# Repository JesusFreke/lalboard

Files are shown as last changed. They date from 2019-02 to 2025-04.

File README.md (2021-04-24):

##### lalboard - A 3D-printed keyboard inspired by the DataHand.

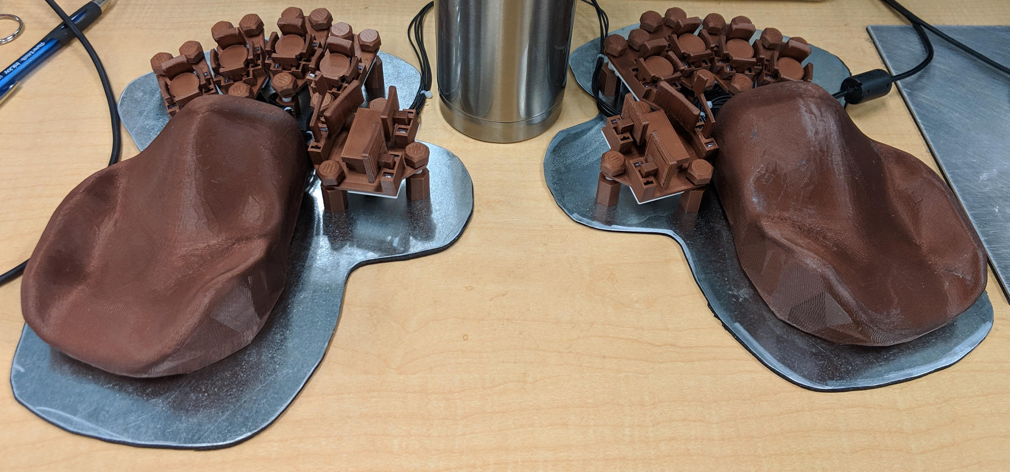
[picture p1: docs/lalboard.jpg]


## Links
[More Images](https://github.com/JesusFreke/lalboard/wiki/Images)

[120 WPM Typing Demo](https://www.youtube.com/watch?v=oMhOIgrdeE0)

[V2 Project Logs (hackaday.io)](http://lalboard.com)

Online viewer for cluster assemblies:
- [finger](https://a360.co/3vxlLLL)
- [left thumb](https://a360.co/3c63TzE)
- [right thumb](https://a360.co/3c6tvws)

## Project Details
I am a long-time user of a DataHand keyboard. With the scarcity and rising cost of second hand
DataHands these days, I wanted to ensure that I always had access to a DataHand-like keyboard. And
so this project was born.

The overall functionality of the lalboard is obviously heavily based on the DataHand, but I designed
all of the specific key mechanisms, etc. from scratch, to be printable on a normal hobby-level
FDM printer.

With my DataHand, I never felt like I could get the keys positioned *quite right* for my hand. So
one of my primary focuses with the lalboard was adjustability. Each key cluster can be independently
adjusted in all 6 degrees of freedom to some extent.

Most parts need to be printed in a very opaque PLA, but there are a few parts that don't work well
in PLA which should be printed in polycarbonate or similar material, for its strength and heat
resistance.

##### Key Mechanisms

All keys use a pair of magnets to provide the clickiness and key return force, and an IR LED and
phototransistor for detecting a keypress. They are all held in place only with magnets, so they
are easily removable for cleaning, etc.

The feel/clickiness of the keys was another focus area. I tried to get them to feel as similar to
those on a DataHand as possible. They require roughly the same amount of force, and have that same
unique clicky feel due to the magnetic holding force.

##### Adjustability

The key clusters have a trio of standoffs that are designed to be mounted onto a steel sheet with
magnets. Each standoff has an adjustable height, and is mounted to the key cluster via a
ball socket. This provides a limited 6 degrees of freedom in adjusting the angle and position of
each key cluster, in order to get it perfectly positioned for your hands.

##### Electronics

This design uses copper traces that are cut from adhesive-backed copper tape using a vinyl cutter,
and applied to the bottom of 3D-printed "pcbs" printed with polycarbonate for its excellent heat
resistance during soldering. There are currently no designs for actual pcbs, but I don't think it
should be difficult to do. If someone wants to tackle that, I'm happy to give pointers or otherwise
help in any way I can :)

Each side of the keyboard uses an independent teensy 2.0 board, and are connected with 4 wires
between them to enable communication via i2c. Only one side of the keyboard actually needs to be
plugged into USB. The teensy's run a modified version of the
[teensyhand](https://github.com/JesusFreke/teensyhand) firmware.

##### Handrest

The handrest was first molded for my wrist in plasticine clay, and then scanned in using the
[meshroom](https://github.com/alicevision/meshroom) photogrammetry software. Since they were molded
for my wrists specifically, I'm not sure how "one-size-fits-all" they are, or how comfortable they
would be for someone else to use.

##### [BOM](https://github.com/JesusFreke/lalboard/wiki/BOM)

##### [Printing tips & instructions](https://github.com/JesusFreke/lalboard/wiki/Printing-tips-&-instructions)

##### [Preparing the Vinyl-cut PCBs](https://github.com/JesusFreke/lalboard/wiki/Vinyl-Cut-PCBs)

--------

Note: This is not an officially supported Google product.

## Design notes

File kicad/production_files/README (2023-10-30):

For generating gerbers: https://jlcpcb.com/help/article/362-how-to-generate-gerber-and-drill-files-in-kicad-7
For generating BOM/CPL: https://dubiouscreations.com/2019/10/21/using-kicad-with-jlcpcb-assembly-service/

tweaks to CPL file:

J1-J7 - remove
J8, J9 - 180 degrees, subtract 1.75 from Y position
U6, U7 - check rotation
U2 - check rotation
Y1 - check rotation

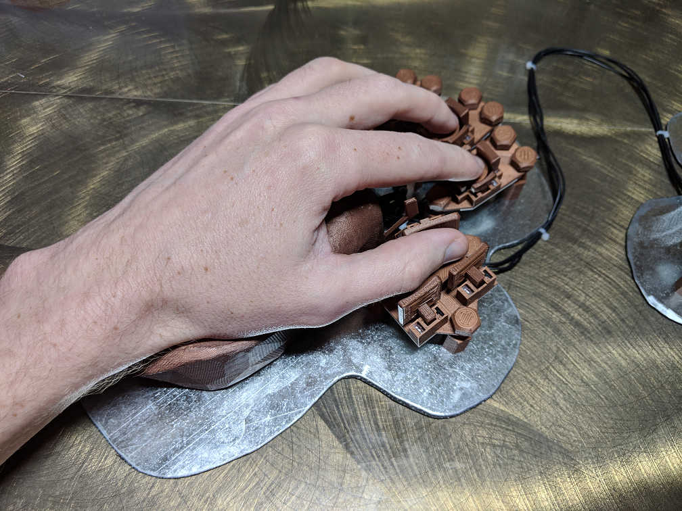
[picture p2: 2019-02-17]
docs/hand.jpg

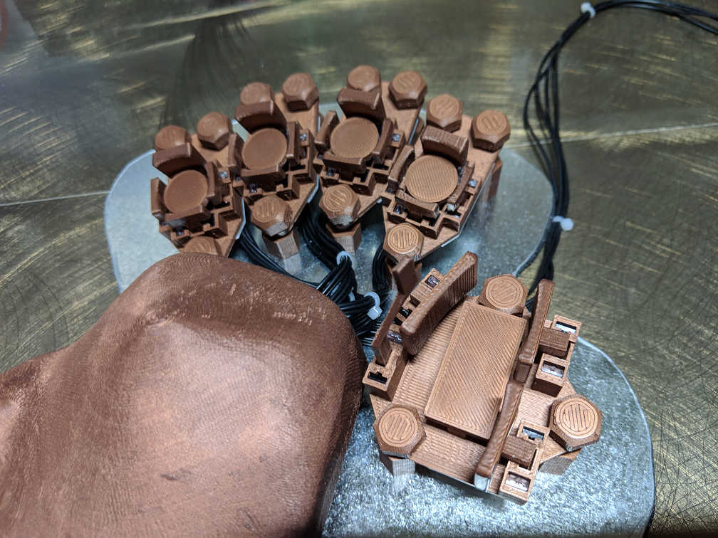
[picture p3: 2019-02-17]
docs/closeup.jpg

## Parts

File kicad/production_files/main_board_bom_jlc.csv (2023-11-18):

Comment | Designator | Footprint | LCSC Part Number
10u | C1 | C_0402_1005Metric | C15525
100n | C2,C5,C6,C9,C12,C13,C14,C15,C16,C17,C19,C20 | C_0402_1005Metric | C307331
4.7u | C4 | C_0402_1005Metric | C23733
1u | C7,C10 | C_0402_1005Metric | C307454
30pF | C8,C11 | C_0402_1005Metric | C1570
CBG201209U500T | FB1,FB2,FB3,FB4 | L_0805_2012Metric | C668236
TYPE-C-31-M-12 | J8,J9 | USB_C_Receptacle_HRO_TYPE-C-31-M-12 | C165948
DMG2301L-7 | Q1,Q2,Q3,Q4,Q5 | SOT-23 | C102619
1.5k | R1 | R_0402_1005Metric | C25867
1k | R2,R3 | C_0402_1005Metric | C11702
10k | R4 | R_0402_1005Metric | C25744
27 | R5,R6 | C_0402_1005Metric | C25100
100k | R7 | R_0402_1005Metric | C25741
390k | R8 | R_0402_1005Metric | C25782
2k | R9,R10,R11,R12,R13 | R_0402_1005Metric_Pad0.72x0.64mm_HandSolder | C4109
5.1k | R14,R15,R16,R17 | R_0402_1005Metric | C25905
Reset | SW1 | SW_TS-1187A-B-A-B | C318884
Boot | SW2 | SW_TS-1187A-B-A-B | C318884
XC6220B331MR | U1 | SOT-23-5 | C3040644
RP2040 | U2 | RP2040-QFN-56 | C2040
W25Q128JVS | U3 | SOIC-8_5.23x5.23mm_P1.27mm | C97521
COS724 | U4,U5 | TSSOP-14_4.4x5mm_P0.65mm | C2685541
USBLC6-2SC6 | U6,U7 | SOT-23-6 | C7519
Crystal_GND24 | Y1 | OSC_X322516MLB4SI | C9002

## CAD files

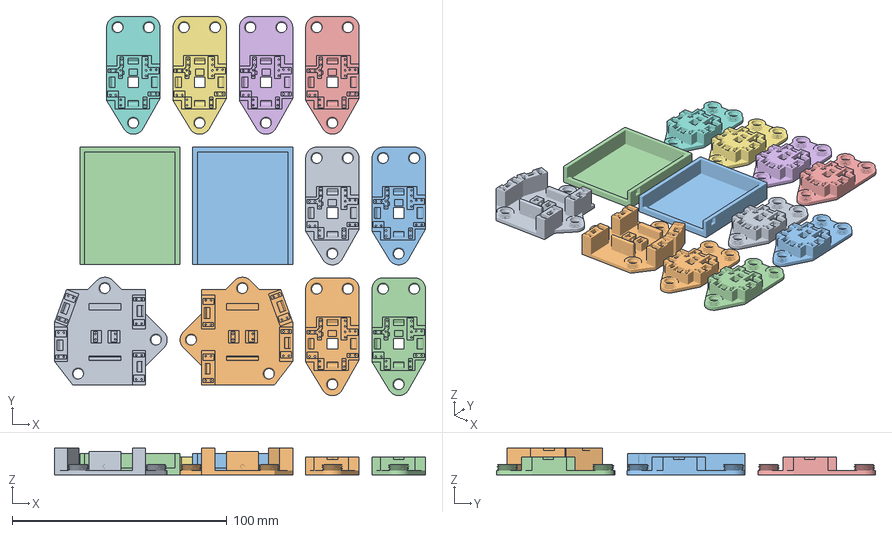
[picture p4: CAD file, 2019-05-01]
configs/clusters.3mf
172.8 x 176.6 x 12.4 mm
cluster.stl
left_thumb_cluster.stl
right_thumb_cluster.stl
central_pcb_tray.stl

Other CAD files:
left_handrest.f3d
test/FingerClusterPlacementTest/absolute_cartesian_and_euler_placement.f3d
test/FingerClusterPlacementTest/absolute_cylindrical_and_support_lengths_placement.f3d
test/FingerClusterPlacementTest/lefthand_relative_cartesian_placement.f3d
test/FingerClusterPlacementTest/lefthand_relative_cartesian_placement_with_gap.f3d
test/FingerClusterPlacementTest/lefthand_relative_cylindrical_placement.f3d
test/FingerClusterPlacementTest/lefthand_relative_cylindrical_placement_with_gap.f3d
test/FingerClusterPlacementTest/righthand_relative_cartesian_placement.f3d
test/FingerClusterPlacementTest/righthand_relative_cartesian_placement_with_gap.f3d
test/FingerClusterPlacementTest/righthand_relative_cylindrical_placement.f3d
test/FingerClusterPlacementTest/righthand_relative_cylindrical_placement_with_gap.f3d
test/ThumbClusterPlacementTest/absolute_cartesian_and_euler_placement_left.f3d
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

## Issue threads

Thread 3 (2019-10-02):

Please create a Kickstarter/Indiegogo/etc

hillelcoren, 2019-10-02:
I would love to buy one of these, how can I help make it happen?

JesusFreke, 2019-10-02:
haha, no :)

I'm happy to put the design up and let people do what they want with it, but I don't particularly want to spend my free time trying to finagle a crowd funding campaign, or building these to sell. Plus, it's honestly not... polished enough to be sold/marketed as an off-the-shelf consumer item.

I might be convinced to sell the raw 3d printed/vinyl cut parts or something though.

Closed 2019-11-05.

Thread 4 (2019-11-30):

7 pin cable length

fi0, 2019-11-30:
I found a source for 7-pin silicone wire with ZH 1.5. How long should I buy? is 6" long enough?

JesusFreke, 2019-11-30:
See https://github.com/JesusFreke/lalboard/wiki/BOM. You'll want 10x of the 6" ones, and one longer one. The longer one is the one that runs between the two sides. I would say probably a minimum of 10" for that one, but 12" or even longer may be better. The longer it is the further apart you can have the 2 sides, of course.

JesusFreke, 2019-11-30:
Also, care to share the source? :) I can add it to the BOM page

HeuristicBishop, 2019-12-03:
I would also greatly appreciate a source!

fi0, 2019-12-03:
Thank you for the clarifications! I'm going to place a custom order from a factory in China.

HeuristicBishop, 2020-04-13:
Not the cheapest in the world but non-silicon premade jumpers can be sourced from digi-key:
Part number: A07ZR07ZR28H102B

JesusFreke, 2020-04-13:
Yeah, the BOM includes links to at least some 150mm cables with PVC insulation. I found a similar 1'/300mm digikey cable and added a link to the BOM.

They'll definitely work, but it's a bit of a pain working with them in such a confined space.

I wasn't familiar with the ZR line. It looks like they're a "press in" connector, that is compatible with the ZH sockets. Interesting. They may be significantly quicker and easier to use when making your own cables, since you don't have painstakingly crimp each individual wire twice. I'll have to try them out.

Closed 2019-12-03.

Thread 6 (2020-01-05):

Wiring tutorials?

GeneralMidi, 2020-01-05:
Hi, this project looks great, maybe not so for a noob. But we'll see. I wasn't able to find any wiring diagrams, or images for wiring the components on your github. Would you point me in the right direction? Thanks.

JesusFreke, 2020-01-05:
The only wires are the ones that run between each cluster and the central board for each hand. And then the ones that run between the two hands. There's a 7-pin jst-zh connector on each cluster, and on each board, and you just plug the wire connector in to either side.

Each cluster, etc. has a little "circuit board" thing, made out of vinyl-cut copper. You can find more information about how I made those on the [wiki page](https://github.com/JesusFreke/lalboard/wiki/Vinyl-Cut-PCBs).

GeneralMidi, 2020-01-06:
Thanks so much for your response, and please excuse my very low experience level. I couldn't find how you wire up the IR leds, photo transistors, the sink drivers, smd resistors, teensys etc. Sorry if this is straight forward, I just like to have a clear idea in my mind how the pieces fit together before I tackle such a project! Thanks for making the project available by the way.

l4u, 2020-01-06:
@GeneralMidi
see https://github.com/JesusFreke/lalboard/blob/master/eagle/mapping.pdf and https://github.com/JesusFreke/lalboard/tree/master/vinyl_cut_pcb for the wiring :)

GeneralMidi, 2020-01-06:
Noob! Thanks so much for pointing me in the right direction...

ampleyfly, 2020-08-13:
I also find the wiring confusing, even given the mapping and the wiki here on Github.
The Eagle files for the center board helps clear that part of it up, but the vinyl cut PCB:s are harder for me to get.
In the mapping.pdf file linked above, the PCB seen to the top left is that for the right thumb, which as far as I can tell is wired differently than the one for the left thumb.
It is also unclear to me which orientation the JST connector has when the thumb or finger boards are viewed from the top. Is pin 1 to the right or to the left?
To help myself sort this out, I have been tinkering with kicad PCB:s for the thumb and finger boards, as well as a wiring diagram using WireViz. Would that be of use to you guys, once I get it down?

JesusFreke, 2020-08-14:
As far as I can tell, the datasheet for the connectors doesn't specify a pin numbering scheme, so there is no common "pin 1" reference to help orient.

The 3d printed part for the pcbs for the individual finger clusters are sized so that the back edge of the connector is flush with the back edge of the pcb in one of the orientations. And with it in that orientation, it gives a tiny bit more space to solder the through-wires just in front if it. But at the end of the day, the orientation doesn't really matter.

There are 3 variables in play - the orientation of both connectors, plus how the wire is... wired (straight-through or reverse). Any combination of those three variables that is mechanically feasible, and ends up with the right pins being connected should work.

I have definitely accidentally soldered connectors backward, and "fixed" it by either soldering the corresponding connector on the central pcb the opposite way, or by reversing how the wire is wired.

That being said, I think the connector pins in the svgs could probably use some labels, so you don't have to try to manually trace things based on known voltage/ground/data pins elsewhere in the circuit.

I would be happy to include any documentation you write and think would be useful :). Either in the project itself (pull request), or in the wiki (PM me and I can add you as a collaborator, allowing you to edit the wiki)

JesusFreke, 2020-08-14:
And yes, the left and right thumbs are wired differently. For one thing, the LEDs and phototransistors are in opposite positions per-key on each side (why?... heck if I know! I didn't even notice that until just now). But even if if they weren't, if you tried to use a mirror copy of the pcb, the components would be wired up in the wrong polarity, since the components themselves aren't mirrored.

JesusFreke, 2020-08-14:
More labels were added in 4e3174a545aaef074abca677f9573e4fc0cdbc51. Hopefully that should make it a bit easier to read :)

JesusFreke, 2020-08-24:
@ampleyfly - I haven't fully looked at everything yet, but it looks like the thumb connector on the central pcb is wired incorrectly. For example, the middle pin should be ground, and 5V should be beside it. But it is wired with the same connections as the finger clusters, with ground and 5V at 1 and 6 (or 7 and 2, depending on which way you number it).

Also, it looks like the thumb and finger boards are 4 layers? It should be possible to do it with 2 layers, which should typically make it cheaper, I would think.

ampleyfly, 2020-08-24:
The central board is imported from the eagle project, and the pinnings on the finger and thumb boards are based on the svg files. Perhaps this mismatch explains the confusion about the wiring in the first place?

I did it in 4 layers because it is a lot easier and takes less effort. While there is a difference in price, 4 layers is still pretty cheap. One the wiring is nailed down, the pcbs could be converted to 2 layers.

ampleyfly, 2020-08-26:
I just realised that the eagle files comes from a pull request from the @IronFox fork, where there are also files for the other pcb:s. I guess either merging those or looking there for how to wire things is better tha redoing the work.

ampleyfly, 2020-08-27:
I updated my branch with a center pcb based on the svg file instead, so now it should at least reflect what's in the svgs accurately! :)

JesusFreke, 2020-08-27:
Yeah, @IronFox is doing his own thing - which is great! But I think not totally compatible.

@IronFox - I'm thinking I might remove the stuff you added in your first pull request to avoid confusion, since it doesn't appear to be compatible with the rest of the "stock" lalboard. But I'd be happy to add a pointer to your project/fork in the README!

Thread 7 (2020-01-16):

Custom handrest?

bofh, 2020-01-16:
Hello, could you please outline the process and provide some tips you used to mold custom handrest? What should be the optimal hand position, height above the table, etc.?

JesusFreke, 2020-01-16:
I molded it out of some plasticene clay first, and then scanned it in use the mesh photogrammetry software. I had never used it before, but used [the tutorial](https://www.youtube.com/watch?v=1D0EhSi-vvc) that Prusa published. Once it was scanned in, I think I cleaned up the mesh in the meshlab software, and then imported it into fusion 360 and simplified the mesh, and added the rectangular cutout in the bottom for the central electronics tray. I don't recall the exact process/steps offhand, sorry :)

As far as the shape, you can take a look at the existing hand rests to get an idea. It needs to be wide enough to hold the tray of course. But other than that, it's mostly up to personal taste? Just kinda whatever feels right for your hand. heh. I'm certainly no ergonomic specialist :)

I would recommend getting the finger and thumb clusters made and at least mechanically assembled and placed onto the steel sheet, and then molding the custom clay handrest in place, so you can see how it feels with your fingers actually in place on the keys, etc.

Closed 2020-04-04.

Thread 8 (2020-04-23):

CAD Models?

thecheatscalc, 2020-04-23:
I apologize if these are available somewhere, but would you be interested in adding your CAD models that generated the STLs? If they're hosted elsewhere, would you mind adding a link in the docs?

JesusFreke, 2020-04-23:
lalboard.py is where all of the models are defined. It uses my [fscad framework](fscad.org) for fusion 360.

thecheatscalc, 2020-04-23:
Aha, I completely missed that. I'll have to try and pull the models in with your fscad framework later. Thanks for clarifying!

Closed 2020-04-23.

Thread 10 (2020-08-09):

Top level assembly

AntonEvmenenko, 2020-08-09:
Hi @JesusFreke!

Let me thank you for creating this very interesting project!

As I understand, you published the Fusion 360 scripts only for individual parts, but currently repository doesn't contain a script that would allow you to generate the entire keyboard:

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

If you added such a script, it would be very cool :)

Of course, if you have your own opinion about it (for example, you do not want to publish this project completely), then it's okay, in this case just close this issue please.

JesusFreke, 2020-08-09:
I did have some scripts for the individual cluster assemblies at one point, but they got out of date as things changed. But the entire project is published. I don't have some hidden script that I'm keeping from you ;)

AntonEvmenenko, 2020-08-10:
> I don't have some hidden script that I'm keeping from you ;)

Haha :)

Ok, thanks for your answer!

Closed 2020-08-10.

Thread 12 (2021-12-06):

Unable to build the Fusion 360 Model: TypeError: create() missing 1 required positional argument: 'z'

ripxorip, 2021-12-06:
Hi, super interesting project! I want to be able to simply build the model and poke around to see all the details in fusion 360. When I try to run the python script like this:

`

$env:PYTHONPATH = "C:\Users\ripxo\AppData\Roaming\Autodesk\Autodesk Fusion 360\API\Python\defs;C:\Users\ripxo\AppData\Roaming\Autodesk\Autodesk Fusion 360\API\AddIns\fscad_addin\src\fscad"

C:/Users/ripxo/AppData/Local/Autodesk/webdeploy/production/849db2e62eaf03702e1167dc7313a6f88a8f47d0/Python/python.exe .\lalboard.py

`

I get the following error:

`
Traceback (most recent call last):
  File ".\lalboard.py", line 27, in <module>
    from fscad import *
  File "C:\Users\ripxo\AppData\Roaming\Autodesk\Autodesk Fusion 360\API\AddIns\fscad_addin\src\fscad\fscad.py", line 1099, in <module>
    class Component(BoundedEntity, ABC):
  File "C:\Users\ripxo\AppData\Roaming\Autodesk\Autodesk Fusion 360\API\AddIns\fscad_addin\src\fscad\fscad.py", line 1121, in Component
    _origin = Point3D.create(0, 0, 0)
TypeError: create() missing 1 required positional argument: 'z'
`

Has the Fusion360 API got updated so that it is messing with fscad somehow? Thanks in advande

ripxorip, 2021-12-06:
I just realized when browsing through the code that the ....\defs folder appeared to be a mock of some kind so I updated the path:

$env:PYTHONPATH = "C:\Users\ripxo\AppData\Local\Autodesk\webdeploy\production\849db2e62eaf03702e1167dc7313a6f88a8f47d0\Api\Python\packages;C:\Users\ripxo\AppData\Roaming\Autodesk\Autodesk Fusion 360\API\AddIns\fscad_addin\src\fscad"

But now it fails to load some DLL:

`
Traceback (most recent call last):
  File ".\lalboard.py", line 20, in <module>
    import adsk.core
  File "C:\Users\ripxo\AppData\Local\Autodesk\webdeploy\production\849db2e62eaf03702e1167dc7313a6f88a8f47d0\Api\Python\packages\adsk\core.py", line 13, in <module>
    from . import _core
ImportError: DLL load failed: The specified module could not be found.
`

ripxorip, 2021-12-06:
(I am trying to run it straight from Powershell since it fails without any info when trying to run the script from within Fusion 360)

ripxorip, 2021-12-06:
I think I am getting somewhere... I have realized that you need IntelliJ and your plugins to inject in to Fusion 360. I have one through the hassle of downloading and installing IDEA and the plugins. I have set up the source of this repo as a project and configured it accordningly. When I now try to build the model I get the following error:

Unhandled exception while importing and running script.
Traceback (most recent call last):
  File "C:/Users/ripxo/AppData/Roaming/Autodesk/Autodesk Fusion 360/API/AddIns/fusion_idea_addin/fusion_idea_addin.py", line 340, in notify
    spec.loader.exec_module(module)
  File "<frozen importlib._bootstrap_external>", line 728, in exec_module
  File "<frozen importlib._bootstrap>", line 219, in _call_with_frames_removed
  File "C:\dev\lalboard\lalboard.py", line 516, in <module>
    def find_tangent_intersection_on_circle(circle: Circle, point: Point3D):
NameError: name 'Circle' is not defined

Seems like something is not imported correctly?

JesusFreke, 2021-12-06:
The script has to be run inside of fusion 360. The easiest way to do this is just by adding it as a script in the "scripts and add-ins" dialog. But if you want to get a full development environment set up, you can install intellij idea (community edition is fine) and use my [fusionidea plugin](https://github.com/JesusFreke/fusionIdea) to inject the script into fusion and run it that way. See [here](https://github.com/JesusFreke/fscad/wiki/Getting-started-with-Intellij-IDEA-(Windows)) for more details on that route - although it looks like this may be slightly out of date. I'll try and get it updated :)

In either case, you'll need to ensure that fscad has been installed in fusion 360. See https://github.com/JesusFreke/fscad/wiki/Installation

ripxorip, 2021-12-06:
Thanks for the reply. I have went down the route of the fusionidea plugin. And this:

Unhandled exception while importing and running script.
Traceback (most recent call last):
File "C:/Users/ripxo/AppData/Roaming/Autodesk/Autodesk Fusion 360/API/AddIns/fusion_idea_addin/fusion_idea_addin.py", line 340, in notify
spec.loader.exec_module(module)
File "", line 728, in exec_module
File "", line 219, in _call_with_frames_removed
File "C:\dev\lalboard\lalboard.py", line 516, in
def find_tangent_intersection_on_circle(circle: Circle, point: Point3D):
NameError: name 'Circle' is not defined

Is infact from Fusion 360 so I have a connection :) I have installed both plugins in Fusion 360, fscad and ideafusion. It seems that when running in Fusion 360 it is having a problem referecing classes from the "from fscad import *" ?

ripxorip, 2021-12-06:
My guess is that something goes wrong when adding the fscad plugin as a dependency?

JesusFreke, 2021-12-06:
Also note that the lalboard.py script itself doesn't actually create any parts. You'll need to run the script for an individual part or for an assembly, in the parts folder. See, e.g. [static_base_left_full_assembly](https://github.com/JesusFreke/lalboard/blob/v2_no_stls/parts/static_base_left_full_assembly/static_base_left_full_assembly.py), which should create the full left-hand side, using a "static" base.

ripxorip, 2021-12-06:
The script failed to run directly in Fusion 360 without any output, so thats why I continued my investigation and installed IntelliJ etc.

JesusFreke, 2021-12-06:
Are you sure fscad is installed as an add-in? And is the add-in running? You may need to set it to auto-run when fusion starts.

JesusFreke, 2021-12-06:
Also, make sure you're on the v2_no_stls branch :). I don't think the main (v1) branch is what you want at this point.

ripxorip, 2021-12-06:
Yeah fscad_addin is running and set to auto-start. Tried the steel_base_left_full_assembly now and it failed:

Unhandled exception while importing and running script.
Traceback (most recent call last):
  File "C:/Users/ripxo/AppData/Roaming/Autodesk/Autodesk Fusion 360/API/AddIns/fusion_idea_addin/fusion_idea_addin.py", line 342, in notify
    module.run({"isApplicationStartup": False})
AttributeError: module '__main__C%3A%5Cdev%5Clalboard%5Clalboard_py' has no attribute 'run'

ripxorip, 2021-12-06:
Yeah Im on the v2_no_stls now :)

JesusFreke, 2021-12-06:
Yeah, looking at the main branch, that Circle error makes sense, since fscad has been slightly restructured, so it requires slightly different imports now. Hopefully the v2_no_stls branch should work fine though.

JesusFreke, 2021-12-06:
Oh, you probably want to restart fusion at this point. Just to clear out any lingering loaded scripts from when you were using the main branch.

ripxorip, 2021-12-06:
Score! It works, managed to run the part manually without IntelliJ straight in Fursion360 :) However using IntelliJ:

Unhandled exception while importing and running script.
Traceback (most recent call last):
  File "C:/Users/ripxo/AppData/Roaming/Autodesk/Autodesk Fusion 360/API/AddIns/fusion_idea_addin/fusion_idea_addin.py", line 342, in notify
    module.run({"isApplicationStartup": False})
AttributeError: module '__main__C%3A%5Cdev%5Clalboard%5Clalboard_py' has no attribute 'run'

Still a win since I now can look at the full model in Fusion 360 :) Thank you very much for this project and for the support

JesusFreke, 2021-12-06:
It looks like it's still trying to run lalboard.py instead of the individual part script

ripxorip, 2021-12-06:
Correct, I am a IDEA noob... First time using it. Now it runs the part script:

Unhandled exception while importing and running script.
Traceback (most recent call last):
  File "C:/Users/ripxo/AppData/Roaming/Autodesk/Autodesk Fusion 360/API/AddIns/fusion_idea_addin/fusion_idea_addin.py", line 342, in notify
    module.run({"isApplicationStartup": False})
  File "C:\dev\lalboard\parts\static_base_left_full_assembly\static_base_left_full_assembly.py", line 83, in run
    lalboard.run_design(design, context=context)
  File "C:\dev\lalboard\lalboard.py", line 3415, in run_design
    filename = module.__file__
AttributeError: 'NoneType' object has no attribute '__file__'

ripxorip, 2021-12-06:
Still very happy that generation using "script" in Fusion 360 works. This project is amazing! Mad skills all over. I will try to build a version sourcing what I can find in terms of magnets etc here in Sweden. Now Im able to tweak it if I need to 👍

ripxorip, 2021-12-06:
Now I got the IntelliJ plugin working as well. In my desperation I messed with the depencies path in IntelliJ, I now remebered that I had to restore it to your instructions and it works :) Once again, a huge thank you!

Closed 2021-12-06.

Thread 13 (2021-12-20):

Azeron

mtsgsd, 2021-12-20:
Did this become the Azeron Gamepad, or did someone steal the idea? This seems to be a dead project now.

JesusFreke, 2021-12-20:
This was inspired by the datahand. I have no knowledge of Azeron's inspiration or heritage. But I would guess it probably took some inspiration from the datahand as well.

Project isn't dead, but currently on hold, as Life Stuff is Happening :)

rafaelpirolla, 2022-01-19:
https://geekhack.org/index.php?topic=93039.0
Azeron thread

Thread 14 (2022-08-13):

Cluster keywell geometry

saesols, 2022-08-13:
Hi, I'm migrating your project to CadQuery + QMK at the moment and have a question.

Is a geometry at the bottom of the keywell more complicated for tactility reasons?

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

JesusFreke, 2022-08-13:
This geometry helps to ensure there isn't a steep overhang angle, for better printability. But I'm not totally sure it's necessary, at that scale.

saesols, 2022-08-13:
Thank you!

wirekang, 2024-09-22:
@scruper Hi. I'm trying to migrate fscad files into cadquery. Can you share your works or give me some advice?

Closed 2022-08-13.

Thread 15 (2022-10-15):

Current version?

DocFreeman, 2022-10-15:
Hi, this is such an intriguing project and I could easily see it becoming popular. I don't see any builds from other people yet though and I've been searching around for them for the last year and change. So... What's the current version? Is this V2 good to build? Is there a V5 sitting in Area 51? Inquiring minds want to know.

qotuzin, 2022-10-21:
I am also incredibly interested in this project, and have similar questions.
I just got my first 3d printer, and although quality is still a big problem, I succesfully printed one of the finger V1 clusters. Just discovered the v2 files and wondering what the main differences are and why they were changed.
Absolutely love your work!

JesusFreke, 2022-10-21:
V2 is in a working-ish state (it's what I'm using as my daily driver), although it's not final. I just kinda got it to a "good enough for me" state, and then life happened and I kinda got busy with other things, and I just haven't picked it back up.

There are a few people who have built one, or are building one. If you want to try, I'm happy to answer questions, but it'll involve a fair bit of figuring things out on your part, as there really isn't any documentation yet. One person in particular is trying out some ideas that may make it easier to manufacture.

My plans for the future involve further improving the design, improving the firmware and making it more appropriate for use by others, and writing some build instructions, etc.

V2 has quite a few changes. Better printability, thicker keys that won't break after ~months of use. An improved mounting system. An actual PCB, and the PCB is easily removable, unlike V1. Better support for generating a static "frame" to hold the handrests and key clusters, once you get the positioning figured out with the adjustable mounts. I'm sure there's more that's not coming to mind :)

AJolly, 2024-03-19:
For anyone finding this in the future, the spiritual commercial successor seems to be: https://svalboard.com/

AtomThe1337, 2024-03-19:
No one in their right mind pays 700+ euros for something 3D printed.

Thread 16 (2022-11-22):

Phototransistors seem to be generally unavailable now

IcedQuinn, 2022-11-22:
Seem to be sold out (Digikey) or marked as won't be stocked (Mouser.)

I put a pin in looking up suitable replacements but I have to figure out what the rules for part substitution are here (i'm not a hardwareblob.)

JesusFreke, 2022-11-22:
Oh, interesting. It looks like LCSC has the related PT908-7C-F, which I believe is the same thing, but just with a clear package instead of the black package. I'm not sure if that would affect anything, but I suspect not, since the PT will be basically entirely enclosed by opaque plastic.

https://lcsc.com/product-detail/Phototransistors_Everlight-Elec-PT908-7C-F_C142281.html

Someone else who is building one made a modified design that uses surface mount components instead, so that may be an option if these become unobtanium.

JesusFreke, 2022-11-22:
liteon LTR-301 looks to be the same form factor and wavelength. although it looks like it might have a bit of a lower sensitivity, so some of the resistor values might need to be tweaked.

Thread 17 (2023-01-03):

Components only on one side of the PCB

C1oover, 2023-01-03:
Version: v2
PCB: cluster
Currently the components of the PCB are distributed on both sides of the PCB. That may not pose a problem during DIY soldering but significantly increases price when opting for automated assembly.
Example: JLC-PCB, one sided ~$15, two sided ~$120
Main Board and Thumb-Cluster already have only one sided components.

I will try to solve this issue during feburary, since I plan to add a Trackball to the thumb cluster and have to edit/order that PCB as well.

JohnnyBau, 2025-02-12:
Trackball would be neat! On sided placement would also be great. How is the progress with the trackball?

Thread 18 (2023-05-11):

Generate parts on Linux without Fusion360

Baehn, 2023-05-11:
Hello,

I would like to generate all parts (i.e. corresponding stl files) on my linux machine which also means that I don't have access to Fusion360. Is this possible? For example, I tried to run "parts/cluster/cluster.py" with "lalboard.Lalboard()" as a context but this is not working.

(great work btw :smiley:  )

JesusFreke, 2023-05-11:
It's not possible, unless you're able to run fusion 360 in wine or in a VM or something.

JesusFreke, 2023-05-11:
@claussen reimplemented the parts in onshape, and has been doing a lot of work on the design though

claussen, 2023-05-11:
@JesusFreke , Looks like a fun project, but I think you are giving me credit for work done by someone else.

morganvenable, 2023-05-11:
Too late to the short username party here 😅

claussen, 2023-05-11:
It's all good.  Just want to ensure credit given where it's due.

Baehn, 2023-05-12:
@morganvenable: are your parts available somewhere?

scruper, 2023-05-13:
Is it worthwhile to reimplement 3D model generation with CadQuery? It might be much easier for newcomers to make adjustments. What do you think?

morganvenable, 2023-05-13:
Not to me personally, but I bet someone would appreciate it.  The fine
details I've had to get into in procedural CAD would've been pretty hairy
in SCAD, and configuration management is pretty heavy too.  Any workflow
that doesn't give live, direct editing of the geometry you're looking at
would've multiplied my work effort and time by... 10x?  Soooooo many little
fiddly bits.

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

Ben-PH, 2025-04-20:
For this to be a truly FOSS project, the modelling will need to be done in a FOSS software as well. onshape and f360 are no-go's. Given the openSCAD diffuculties by nature of this project, maybe FreeCAD would be the way to go?

I'm inclined to do some sort of fork and bring this up in freeCAD. I hate FreeCAD for its usability, but beats having this project beholden to closed sauce.

JesusFreke, 2025-04-20:
Be my guest ;)

madnificent, 2025-08-10:
@Ben-PH Did you start on a FreeCAD conversion?

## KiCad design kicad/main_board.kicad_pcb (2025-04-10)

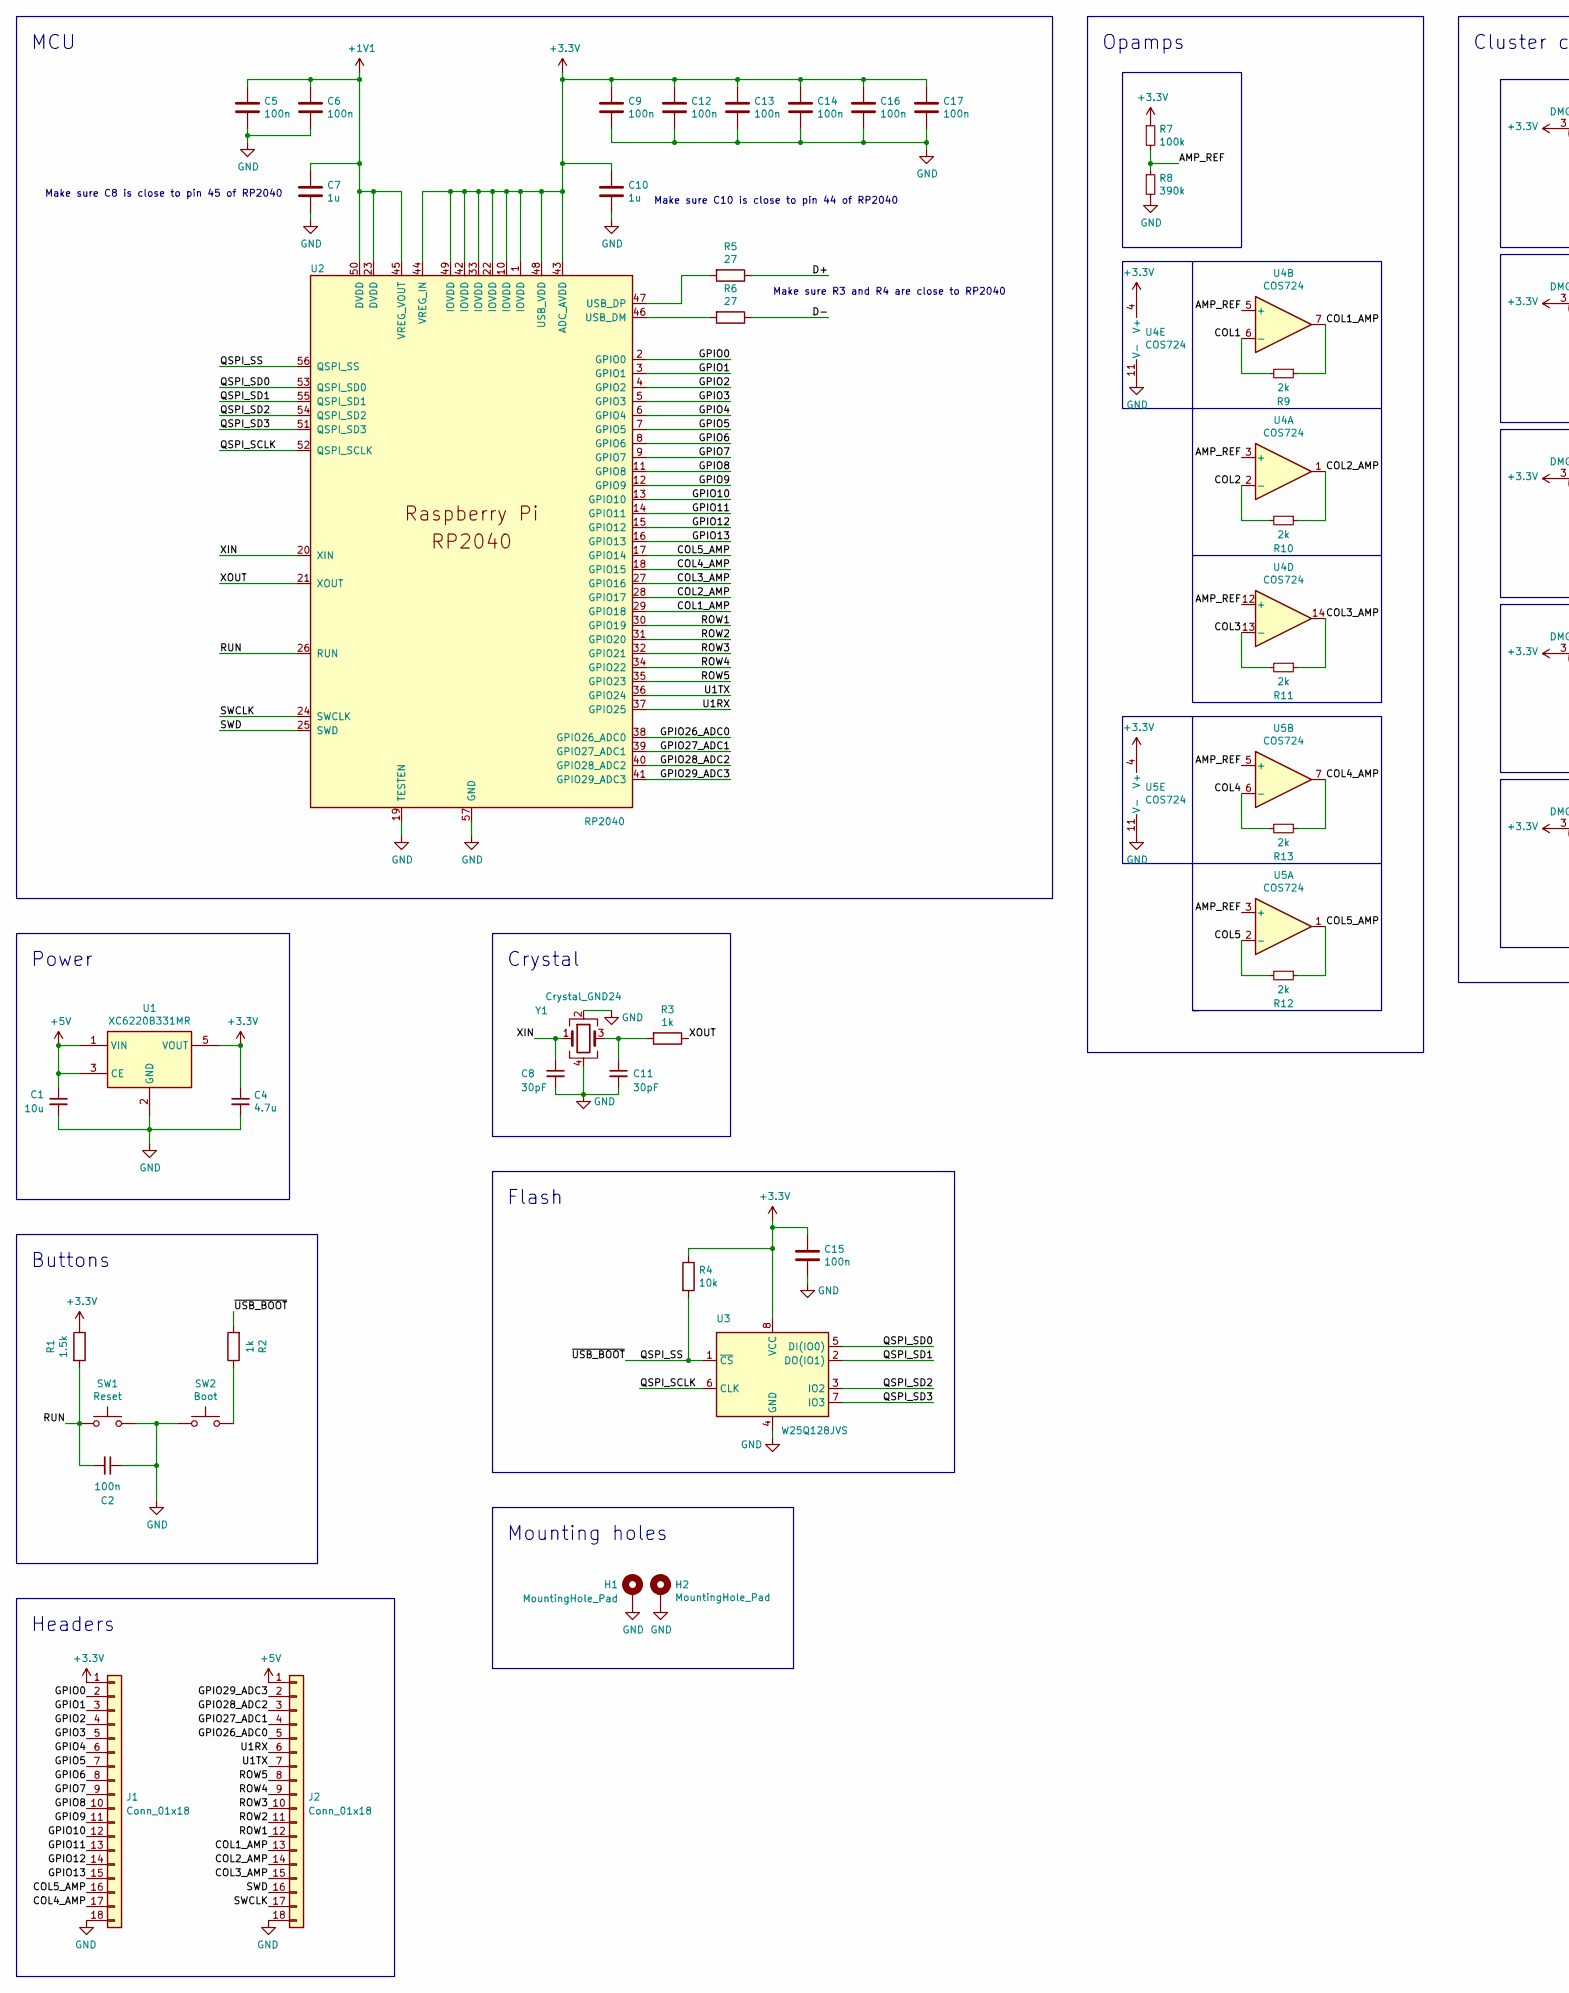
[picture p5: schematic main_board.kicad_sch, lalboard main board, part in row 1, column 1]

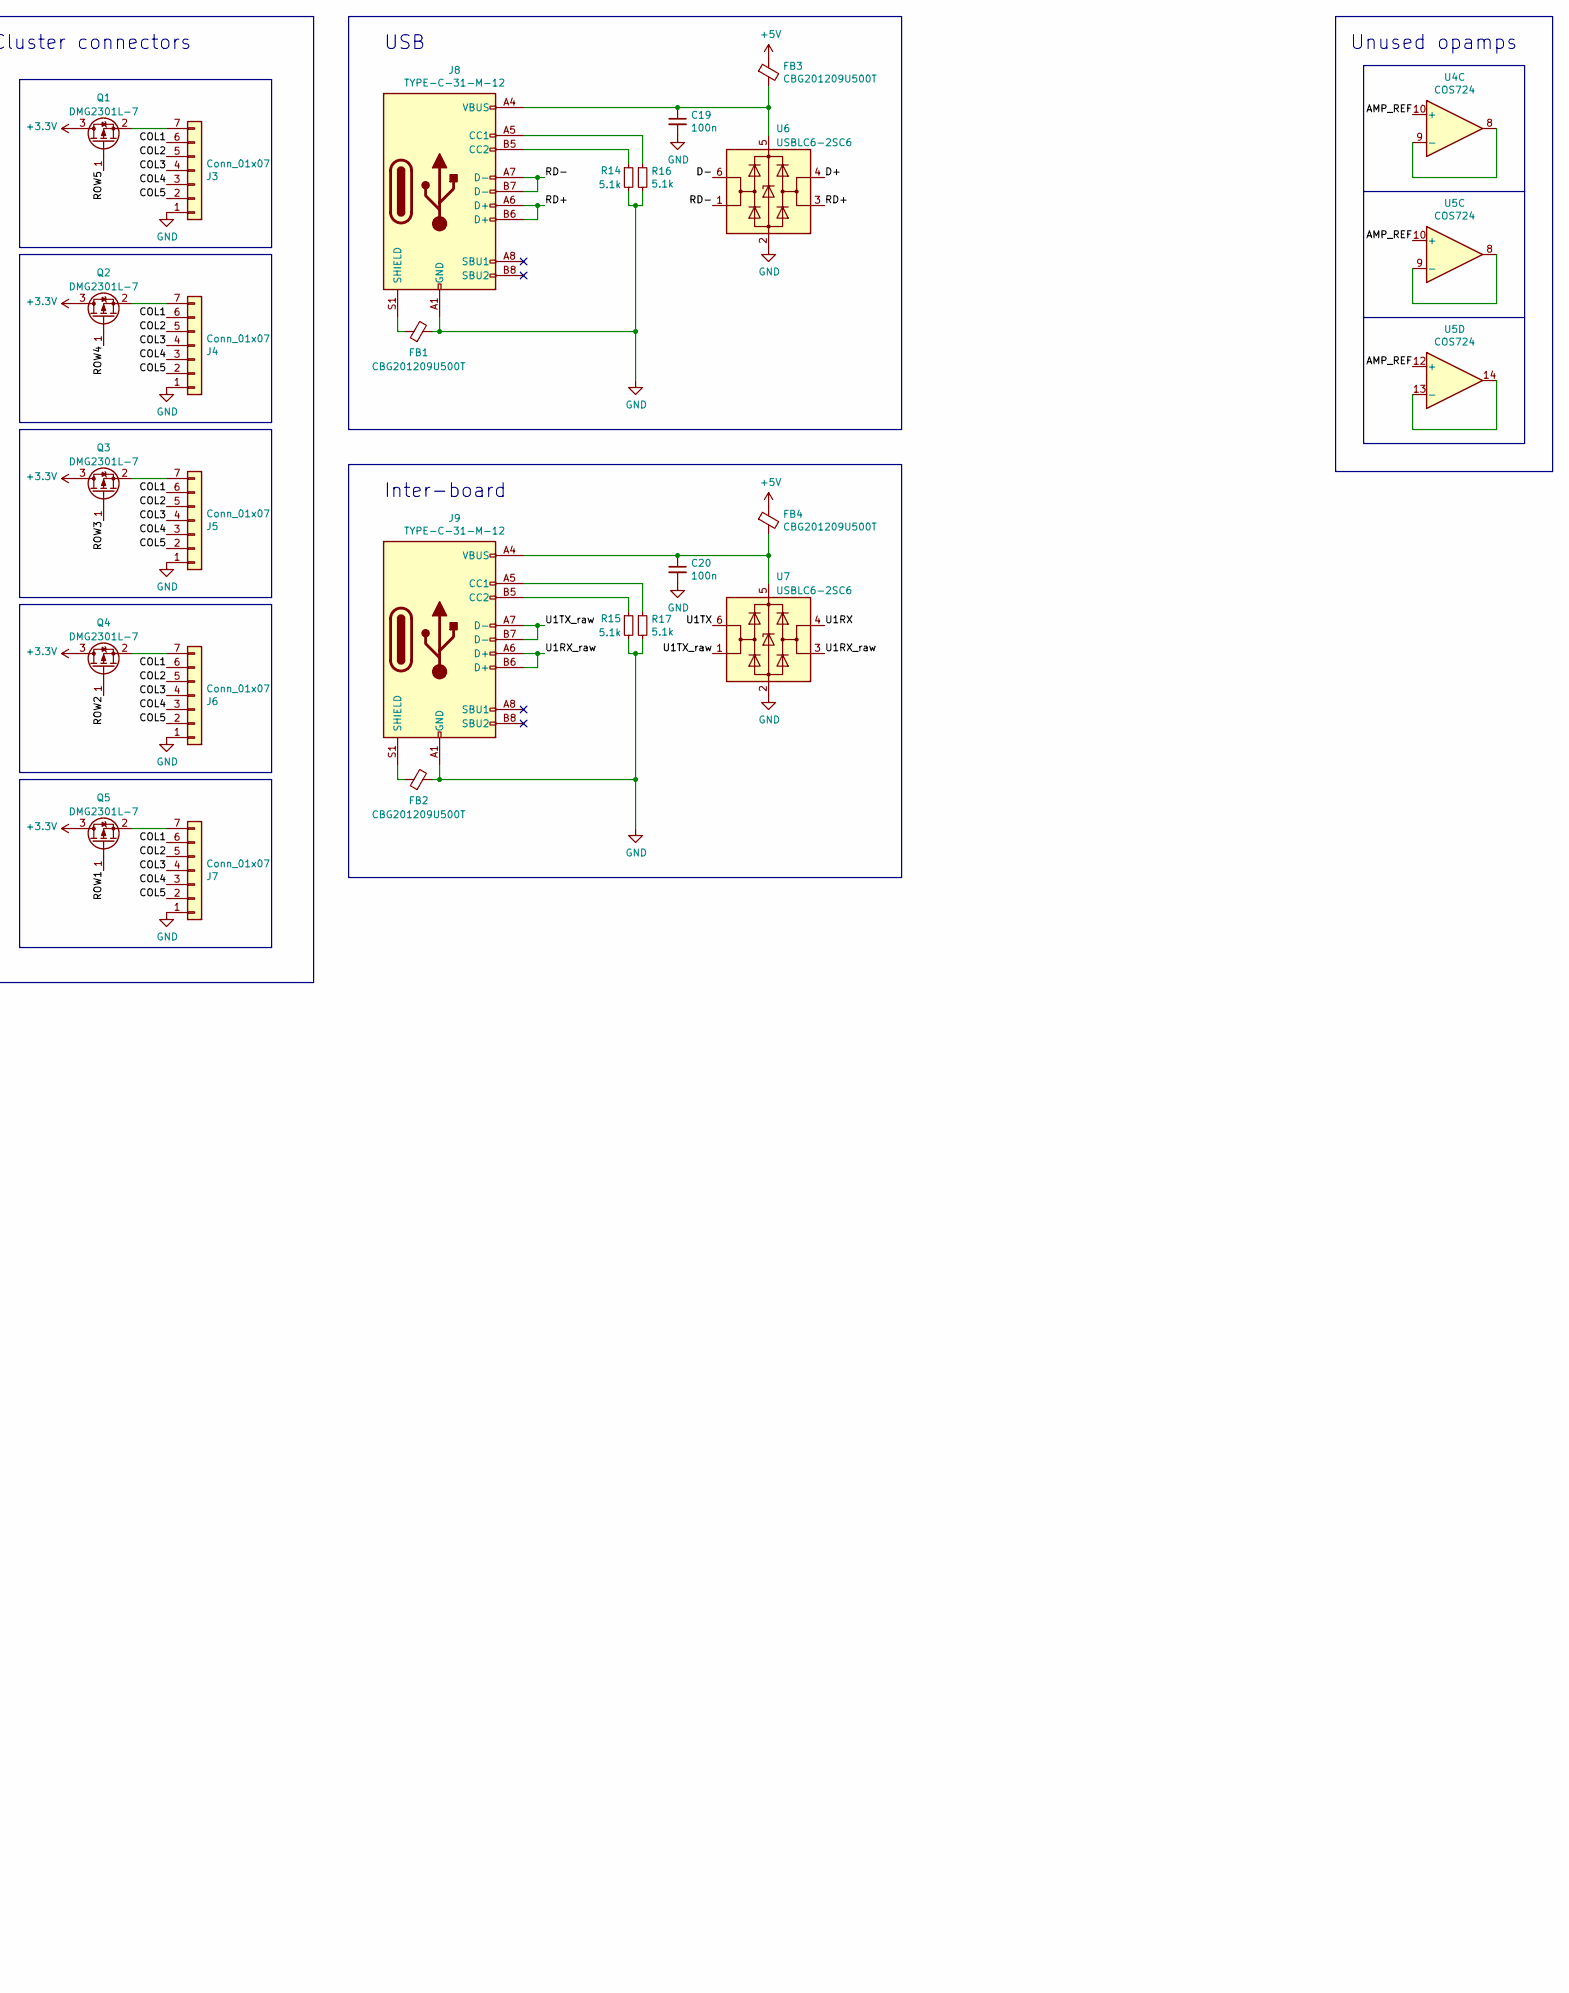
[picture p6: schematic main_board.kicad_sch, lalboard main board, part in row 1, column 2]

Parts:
C1: 10u; C_0402_1005Metric; JLCPCB P/N C15525
C2, C5, C6, C9, C12, C13, C14, C15, C16, C17, C19, C20: 100n; C_0402_1005Metric; JLCPCB P/N C307331
C4: 4.7u; C_0402_1005Metric; JLCPCB P/N C23733
C7, C10: 1u; C_0402_1005Metric; JLCPCB P/N C307454
C8, C11: 30pF; C_0402_1005Metric; JLCPCB P/N C1570
FB1, FB2, FB3, FB4: CBG201209U500T; L_0805_2012Metric; JLCPCB P/N C668236
H1, H2: MountingHole_Pad; MountingHole_3.2mm_M3_DIN965_Pad
J1, J2: Conn_01x18; PinHeader_1x18_P2.54mm_Vertical
J3, J4, J5, J6, J7: Conn_01x07; JST_ZH_B7B-ZR_1x07_P1.50mm_Vertical
J8, J9: TYPE-C-31-M-12; USB_C_Receptacle_HRO_TYPE-C-31-M-12; JLCPCB P/N C165948
Q1, Q2, Q3, Q4, Q5: DMG2301L-7; SOT-23; JLCPCB P/N C102619
R1: 1.5k; R_0402_1005Metric; JLCPCB P/N C25867
R2, R3: 1k; C_0402_1005Metric; JLCPCB P/N C11702
R4: 10k; R_0402_1005Metric; JLCPCB P/N C25744
R5, R6: 27; C_0402_1005Metric; JLCPCB P/N C25100
R7: 100k; R_0402_1005Metric; JLCPCB P/N C25741
R8: 390k; R_0402_1005Metric; JLCPCB P/N C25782
R9, R10, R11, R12, R13: 2k; R_0402_1005Metric_Pad0.72x0.64mm_HandSolder; JLCPCB P/N C4109
R14, R16, R17: 5.1k; R_0402_1005Metric; JLCPCB P/N C25905
R15: 5.1k; R_0402_1005Metric; JLCPCB C25905
SW1: Reset; SW_TS-1187A-B-A-B; JLCPCB P/N C318884
SW2: Boot; SW_TS-1187A-B-A-B; JLCPCB P/N C318884
U1: XC6220B331MR; SOT-23-5; JLCPCB P/N C3040644
U2: RP2040; RP2040-QFN-56; JLCPCB P/N C2040
U3: W25Q128JVS; SOIC-8_5.23x5.23mm_P1.27mm; JLCPCB P/N C97521
U4, U5: COS724; TSSOP-14_4.4x5mm_P0.65mm; JLCPCB P/N C2685541
U6, U7: USBLC6-2SC6; SOT-23-6; JLCPCB P/N C7519
Y1: Crystal_GND24; OSC_X322516MLB4SI; JLCPCB P/N C9002

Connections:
+1V1: C5.1, C6.1, C7.1, U2.23 (DVDD), U2.45 (VREG_VOUT), U2.50 (DVDD)
+3.3V: C4.1, C9.1, C10.1, C12.1, C13.1, C14.1, C15.1, C16.1, C17.1, J1.1, Q1.3 (D), Q2.3 (D), Q3.3 (D), Q4.3 (D), Q5.3 (D), R1.1, R4.1, R7.1, U1.5 (VOUT), U2.1 (IOVDD), U2.10 (IOVDD), U2.22 (IOVDD), U2.33 (IOVDD), U2.42 (IOVDD), U2.43 (ADC_AVDD), U2.44 (VREG_IN), U2.48 (USB_VDD), U2.49 (IOVDD), U3.8 (VCC), U4.4 (V+), U5.4 (V+)
+5V: C1.1, FB3.1, FB4.1, J2.1, U1.1 (VIN), U1.3 (CE)
/AMP_REF: R7.2, R8.1, U4.3 (+), U4.5 (+), U4.10 (+), U4.12 (+), U5.3 (+), U5.5 (+), U5.10 (+), U5.12 (+)
/COL1: J3.6, J4.6, J5.6, J6.6, J7.6, R9.2, U4.6 (-)
/COL1_AMP: J2.13, R9.1, U2.29 (GPIO18), U4.7
/COL2: J3.5, J4.5, J5.5, J6.5, J7.5, R10.2, U4.2 (-)
/COL2_AMP: J2.14, R10.1, U2.28 (GPIO17), U4.1
/COL3: J3.4, J4.4, J5.4, J6.4, J7.4, R11.2, U4.13 (-)
/COL3_AMP: J2.15, R11.1, U2.27 (GPIO16), U4.14
/COL4: J3.3, J4.3, J5.3, J6.3, J7.3, R13.2, U5.6 (-)
/COL4_AMP: J1.17, R13.1, U2.18 (GPIO15), U5.7
/COL5: J3.2, J4.2, J5.2, J6.2, J7.2, R12.2, U5.2 (-)
/COL5_AMP: J1.16, R12.1, U2.17 (GPIO14), U5.1
/D+: R5.1, U6.4 (I/O2)
/D-: R6.1, U6.6 (I/O1)
/GPIO0: J1.2, U2.2 (GPIO0)
/GPIO1: J1.3, U2.3 (GPIO1)
/GPIO2: J1.4, U2.4 (GPIO2)
/GPIO3: J1.5, U2.5 (GPIO3)
/GPIO4: J1.6, U2.6 (GPIO4)
/GPIO5: J1.7, U2.7 (GPIO5)
/GPIO6: J1.8, U2.8 (GPIO6)
/GPIO7: J1.9, U2.9 (GPIO7)
/GPIO8: J1.10, U2.11 (GPIO8)
/GPIO9: J1.11, U2.12 (GPIO9)
/GPIO10: J1.12, U2.13 (GPIO10)
/GPIO11: J1.13, U2.14 (GPIO11)
/GPIO12: J1.14, U2.15 (GPIO12)
/GPIO13: J1.15, U2.16 (GPIO13)
/GPIO26_ADC0: J2.5, U2.38 (GPIO26_ADC0)
/GPIO27_ADC1: J2.4, U2.39 (GPIO27_ADC1)
/GPIO28_ADC2: J2.3, U2.40 (GPIO28_ADC2)
/GPIO29_ADC3: J2.2, U2.41 (GPIO29_ADC3)
/QSPI_SCLK: U2.52 (QSPI_SCLK), U3.6 (CLK)
/QSPI_SD0: U2.53 (QSPI_SD0), U3.5 (DI(IO0))
/QSPI_SD1: U2.55 (QSPI_SD1), U3.2 (DO(IO1))
/QSPI_SD2: U2.54 (QSPI_SD2), U3.3 (IO2)
/QSPI_SD3: U2.51 (QSPI_SD3), U3.7 (IO3)
/QSPI_SS: R2.2, R4.2, U2.56 (QSPI_SS), U3.1 (~CS)
/RD+: J8.A6 (D+), J8.B6 (D+), U6.3 (I/O2)
/RD-: J8.A7 (D-), J8.B7 (D-), U6.1 (I/O1)
/ROW1: J2.12, Q5.1 (G), U2.30 (GPIO19)
/ROW2: J2.11, Q4.1 (G), U2.31 (GPIO20)
/ROW3: J2.10, Q3.1 (G), U2.32 (GPIO21)
/ROW4: J2.9, Q2.1 (G), U2.34 (GPIO22)
/ROW5: J2.8, Q1.1 (G), U2.35 (GPIO23)
/RUN: C2.2, R1.2, SW1.1, U2.26 (RUN)
/SWCLK: J2.17, U2.24 (SWCLK)
/SWD: J2.16, U2.25 (SWD)
/U1RX: J2.6, U2.37 (GPIO25), U7.4 (I/O2)
/U1RX_raw: J9.A6 (D+), J9.B6 (D+), U7.3 (I/O2)
/U1TX: J2.7, U2.36 (GPIO24), U7.6 (I/O1)
/U1TX_raw: J9.A7 (D-), J9.B7 (D-), U7.1 (I/O1)
/XIN: C8.1, U2.20 (XIN), Y1.1
/XOUT: R3.1, U2.21 (XOUT)
GND: C1.2, C2.1, C4.2, C5.2, C6.2, C7.2, C8.2, C9.2, C10.2, C11.2, C12.2, C13.2, C14.2, C15.2, C16.2, C17.2, C19.2, C20.2, FB1.2, FB2.2, H1.1, H2.1, J1.18, J2.18, J3.1, J4.1, J5.1, J6.1, J7.1, J8.A1 (GND), J8.A12 (GND), J8.B1 (GND), J8.B12 (GND), J9.A1 (GND), J9.A12 (GND), J9.B1 (GND), J9.B12 (GND), R8.2, R14.2, R15.2, R16.2, R17.2, SW1.2, SW2.2, U1.2 (GND), U2.19 (TESTEN), U2.57 (GND), U3.4 (GND), U4.11 (V-), U5.11 (V-), U6.2 (GND), U7.2 (GND), Y1.2, Y1.4
unnamed: C11.1, R3.2, Y1.3
unnamed: J3.7, Q1.2 (S)
unnamed: J4.7, Q2.2 (S)
unnamed: J5.7, Q3.2 (S)
unnamed: J6.7, Q4.2 (S)
unnamed: J7.7, Q5.2 (S)
unnamed: J8.A5 (CC1), R16.1
unnamed: J8.B5 (CC2), R14.1
unnamed: FB1.1, J8.S1 (SHIELD)
unnamed: J9.A5 (CC1), R17.1
unnamed: J9.B5 (CC2), R15.1
unnamed: FB2.1, J9.S1 (SHIELD)
unnamed: R2.1, SW2.1
unnamed: R6.2, U2.46 (USB_DM)
unnamed: R5.2, U2.47 (USB_DP)
unnamed: U4.8, U4.9 (-)
unnamed: U5.8, U5.9 (-)
unnamed: U5.13 (-), U5.14
unnamed: C19.1, FB3.2, J8.A4 (VBUS), J8.A9 (VBUS), J8.B4 (VBUS), J8.B9 (VBUS), U6.5 (VBUS)
unnamed: C20.1, FB4.2, J9.A4 (VBUS), J9.A9 (VBUS), J9.B4 (VBUS), J9.B9 (VBUS), U7.5 (VBUS)

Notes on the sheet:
Cluster connectors
Make sure R3 and R4 are close to RP2040
USB
Power
Headers
Buttons
Make sure C8 is close to pin 45 of RP2040
Opamps
Unused opamps
MCU
Inter-board
Crystal
Mounting holes
Make sure C10 is close to pin 44 of RP2040
Flash

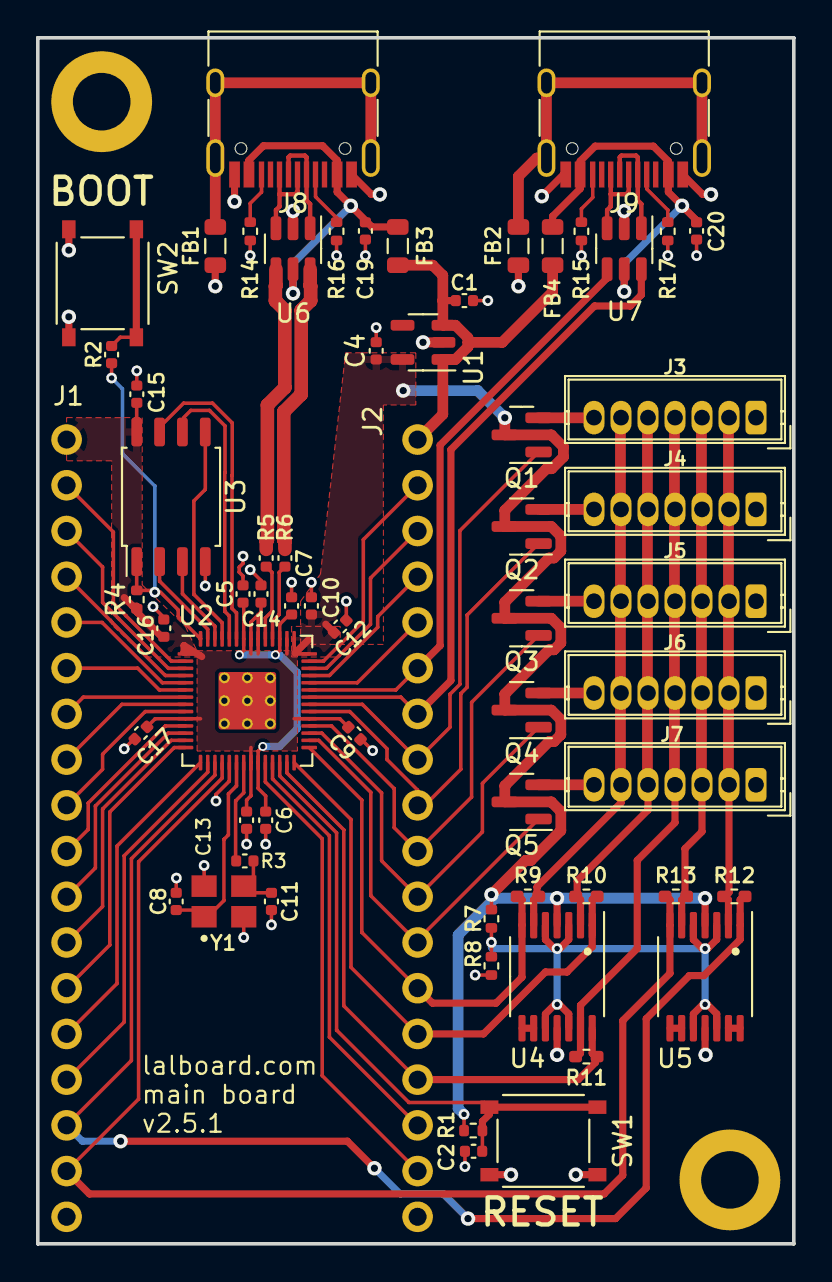
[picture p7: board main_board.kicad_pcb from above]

Board: 2 copper layers, 42.0 x 67.0 mm, 65 parts (0 on the bottom side), 77 nets.

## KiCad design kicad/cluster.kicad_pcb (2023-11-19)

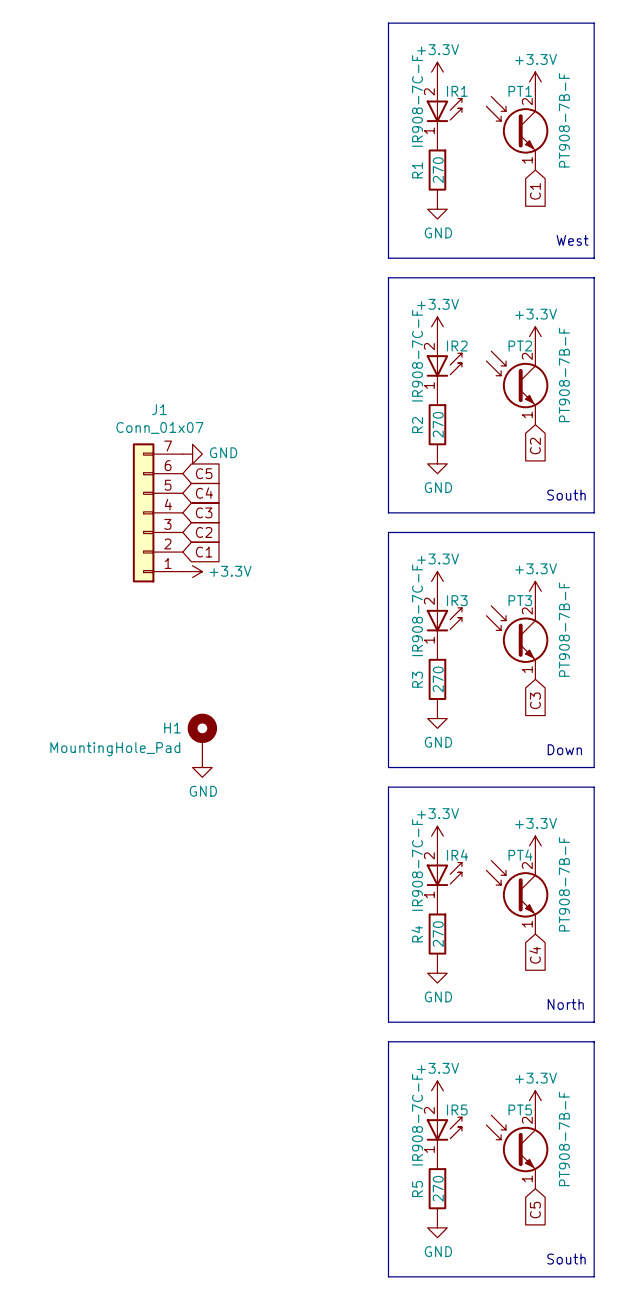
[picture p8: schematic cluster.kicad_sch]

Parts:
H1: MountingHole_Pad; MountingHole_3.2mm_M3_DIN965_Pad
IR1, IR2, IR3, IR4, IR5: IR908-7C-F
J1: Conn_01x07; JST_ZH_S7B-ZR_1x07_P1.50mm_Horizontal
PT1, PT2, PT3, PT4, PT5: PT908-7B-F; PT908-7C-F
R1, R2, R3, R4, R5: 270; R_0805_2012Metric_Pad1.20x1.40mm_HandSolder

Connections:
+3.3V: IR1.2 (A), IR2.2 (A), IR3.2 (A), IR4.2 (A), IR5.2 (A), J1.1, PT1.2 (C), PT2.2 (C), PT3.2 (C), PT4.2 (C), PT5.2 (C)
C1: J1.2, PT1.1 (E)
C2: J1.3, PT2.1 (E)
C3: J1.4, PT3.1 (E)
C4: J1.5, PT4.1 (E)
C5: J1.6, PT5.1 (E)
GND: H1.1, J1.7, R1.1, R2.1, R3.1, R4.1, R5.1
unnamed: IR1.1 (K), R1.2
unnamed: IR2.1 (K), R2.2
unnamed: IR3.1 (K), R3.2
unnamed: IR4.1 (K), R4.2
unnamed: IR5.1 (K), R5.2

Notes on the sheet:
Down
North
West
South

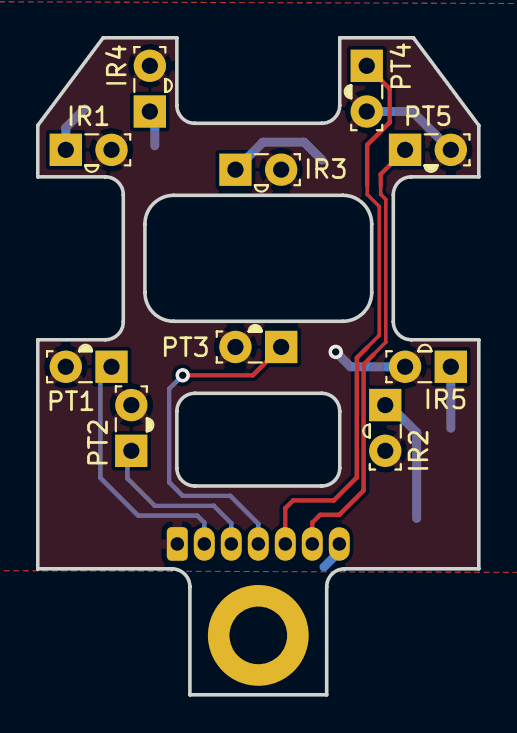
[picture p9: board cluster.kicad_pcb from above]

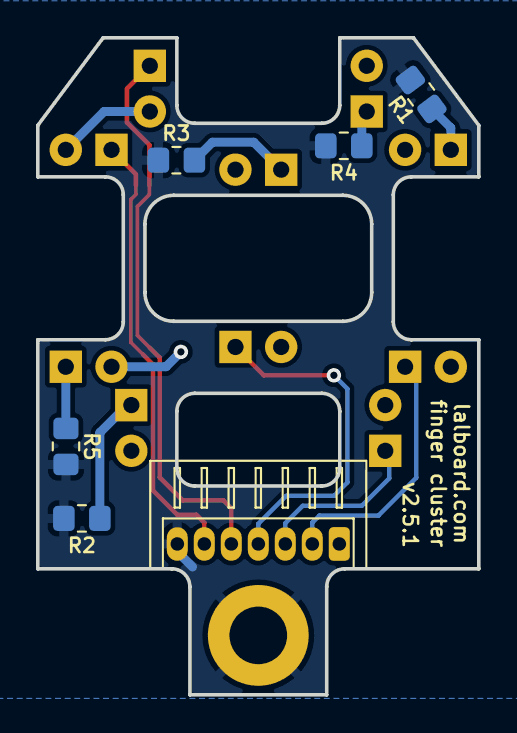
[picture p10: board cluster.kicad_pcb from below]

Board: 2 copper layers, 24.5 x 36.5 mm, 17 parts (6 on the bottom side), 12 nets.

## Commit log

2019-02-11 Fix up the placement of the groove and magnet hole on the side key
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2019-02-11 Add the back extension for the module
    Also:
    - using align_to to place the central led/phototransistor cavities
    - fix up calls to Component.bodies(), now that it's a property
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2019-02-11 Fillet for the edges on the central magnet riser
    This should help reduce binding when pressing on the edge of the center
    key
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2019-02-11 Tweak the retaining groove size and depth for the side keys
    This makes it a bit deeper, so the drooping overhangs don't fall all the
    way to the bed and prevent the groove from gripping.
    This also shrinks the width of the groove a bit, to give a bit more space
    between it and the magnet hole, for better printability
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2019-02-11 Shorten the screwball bases
    This should make it roughly the same threaded length as the part of the
    screwball that sticks out of the base
2019-02-11 Embiggen the screw hole in the screwball base just a bit
    On the longer screws in particular, there was too much friction to easily
    screw it in all the way
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2019-02-11 Strengthen the ballscrew neck
    The screws were breaking too easily. They always failed at the joint
    between the start of neck and the end of the screws.
    This increases the diameter of the neck, so it can bond to the lower
    layers better.
    This also lengthens the neck, because the upper few threads weren't
    actually usable, and were slightly reducing the range of motion of the
    joint
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2019-02-11 Update the hand rest to have a slightly higher cavity
    The previous hand rest wouldn't fit over the teesy with a 90 degree
    micro usb adapter inserted. Also, all the wires from the key modules were
    a bit of a tight fit.
    [hand rest.f3d]
2019-02-11 Tweak the design of the center key
    There's now a single post in the middle of the key, along with a protrusion
    to block the light when pressed. In the cluster, there's a central hole
    that the post is inserted in to.
    The post is also lengthened, so it extends to the bottom of the cluster in
    the neutral position, which requires a corresponding hole in the PCB now
    too.
    And finally the post is enlarged a bit for a smaller clearance with the
    central hole in the cluster.
    This makes the central key more stable, so it doesn't feel as "wobbly",
    and less prone to binding.
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2019-02-11 Add a rim and profiled post for the center key
    This adds an outer rim on the underside of the key, so that the key stops
    before where the post meets the key. This helps to prevent binding, since
    it can be hard to smooth that area right up against the key bottom.
    This also adds a bit of a profile for the post, so that the middle is
    slightly smaller. This also helps reduce binding, since only the top and
    bottom of the post should touch the post hole now, instead of the entire
    length of the post.
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2019-02-23 Make the center down key post a square
    The previous circular post with a flat face had a tendency to get wedged
    into the hole if the key was rotated while pressing it
    [center_key.stl, cluster.stl, cluster_pcb.stl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]
2019-02-23 Rotate the magnets in the main key cluster 45 degrees
    This gets rid of the troublesome bridge over the top of the magnet hole.
    There always seemed to be drooping plastic there that would interfere with
    inserting the magnets, requiring excessive force to force the excess
    plastic out of the way
    [center_key.stl, cluster.stl, long_side_key.stl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]
2019-02-24 Increase the margin on the bottom of the clusters around the ball socket to .8mm
    The narrow .4mm line on the outside would sometimes not get good bed
    adhesion and pull up while printing
    [cluster.stl, cluster_pcb.stl, cluster_pcb_sketch.dxf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]
2019-02-24 Update the vinyl cutter svgs based on the last few changes
    - Rerouted some traces to avoid the larger square hole in the main cluster
    - Updated the outline for the main and thumb clusters
    Also a few other minor cleanup fixes.
2019-02-25 Increase the height of the light interruptor on the center down key
    It wasn't blocking enough light to trigger the key
    [center_key.stl]
2019-02-25 Make the middle of the center key post thinner
    There tends to be some layer irregularities on the post where the magnet
    hole ends. With a straight post, those irregularies have to be filed/cut
    down for a proper fit. This reduces the impact of the irregularities,
    so that only the front face of the post (with the magnet) should need to
    be cleaned up.
    [center_key.stl]
2019-02-26 Remove the fillet on the inner edge of the light interruptor on the center key
    This increases the amount of light blocked
    [center_key.stl]
2019-02-26 Extend the walls in front of the led/phototransistor for the center key
    This should reduce the amount of that light that leaks around the side
    of the light interruptor on the center key
    [cluster.stl]
2019-02-28 Change the rotation of the magnet pair for the central down key back to horizontal
    The rotated magnet doesn't feel quite as clicky
    [center_key.stl, cluster.stl]
2019-02-28 Reduce the offset of the side key magnet.
    After rotating the magnets, the key actuation force feels a bit too low
    [short_side_key.stl]
2019-02-28 Increase the size of the magnet hole in the side keys
    After rotating the magnet, the void was a bit too small
    [long_side_key.stl, short_side_key.stl]
2019-02-28 Move the center key magnet down a bit
    This places the magnet more centrally on the key post, which makes it
    easier to insert -- The light interruptor nubbin on the back doesn't
    interfere with plier placement on the back of the post.
    [center_key.stl, cluster.stl]
2019-03-01 Make the bottom horizontal for the magnet holes for the central key
    The sides should be sloped, but the bottom shouldn't
    [center_key.stl, cluster.stl]
2019-03-01 Get rid of the peaked magnet hole, and move the center magnets down a bit more
    The peaked magnet hole worked, but I didn't particularly like how it looked.
    This changes it back to the older squarish magnet hole.
    The nubbin on the center key was still interfering with the pliers a bit
    when inserting the magnet, so this also moves the magnets down a bit
    further.
    [center_key.stl, cluster.stl]
2019-03-01 Increase the y size of the central post by .1
    The central hole is square, and since there is no gap between the
    front face of the central post and the hole, the gap on the back side is
    twice as large as that on the 2 sides.
    This increases the size of the post so the gap between the post and hole
    on the back and sides is the same.
    [center_key.stl]
2019-03-14 Tweak the magnet height on the thumb side keys
    They had become slightly offset from the cluster magnet after the magnet
    rotation change
    [inner_thumb_key.stl, left_thumb_mode_key.stl, outer_lower_thumb_key.stl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]
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2019-03-14 Increase the width of the groove on the back of the thumb mode key
    Due to the way the mode key in particular tends to get torqued, there would
    be an annoying click as the groove just catches on the corresponding ridge,
    and then slips past it.
    [left_thumb_mode_key.stl, right_thumb_mode_key.stl]
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2019-05-01 Add slic3r .3mf plate file for finger/thumb clusters and the central pcb holders.
    This is a "known good" working config for my prusa mk2.5 printer.
    [clusters.3mf]
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2019-08-01 Increase vertical space below board frame to account for longer Teensy pins
    [rest bottom 6.STL]
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2020-06-29 Switch to a 1x1x1mm magnet for the center down keys
    The previous 1/16" cube magnets needed to be partially demagnetized, in
    order to get a low enough key force. But I was able to find some N50
    1x1x1mm magnets that work perfectly as-is, without the need to partially
    demagnetize them.
    [center_key.stl]
2020-06-29 Add a small cutout to help with inserting the "lower outer" magnet on the thumb
    [left_thumb_cluster.stl, right_thumb_cluster.stl]
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2020-08-14 Fix the right handrest
    It was previously the same as the left hand side.
    [right_handrest.stl]
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2020-10-08 Widen the key stems for the side keys.
    This tweaks the positioning of the optical components to maximize the space
    available for the key stems. This will hopefully strengthen the key stems
    and help prevent fatique and cracking in the area around the magnet.
    That is the area with the least amount of plastic, and it's also where
    the top of the key backstop is, so any bending force on the key tends to be
    concentrated there.
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2020-10-17 Insert LEDs/PTs from the bottom
    This makes it so that the PCB can be removed from the cluster without
    having to unsolder all the LEDs/PTs.
    Previously, the pcb was held on via the soldered leads of the LEDs/PTs.
    The new design doesn't yet have an attachment mechanism, so that will be
    implemented in a later change.
    As part of this change, the LED part was switched out to a similar part
    that has the same form factor as the phototransistor. This is a slightly
    smaller part, so everything was adjusted accordingly.
    The height of all of the LEDs/PTs was tweaked slightly, so the top is even
    with the top of the cluster, instead of being inset just slightly. This
    will make it easy to insert them at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
2020-10-20 Widen the hole for the center key nub
    This reduces the chance of the nub binding on the sides, when the key is
    rotated while being pressed.
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2020-10-20 Make the light interruptor post on the center key a bit thinner
    The hole was made a bit thinner in the cluster refactor, and this helps
    to keep it from binding on the side
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2020-10-26 Minor housecleaning for the cluster
    1. return the clips from full_cluster
    2. refactor the clip part scripts to use full_cluster
    3. add some component names
    4. flip the cluster over when created via its part script, so it's in
    the correct orientation for printing
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2020-10-26 Remove the eagle schematics
    This is for IronFox's fork of the datahand, and I think is slightly
    incompatible with this version.
    You can find IronFox's fork at https://github.com/IronFox/lalboard
    [center.brd, center.sch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]
2020-10-29 Switch out all the ballscrew designs for the new magnetic screw designs
    Instead of having different base sizes, there's just a short base, but
    then there are different sized extensions that you can add to get the
    desired length.
    This also reduces the number of screws to 2. A tiny one for when you need
    a really low clearance (i.e. the front of the pinky clusters), and a
    somewhat longer one that can be used everywhere else.
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2020-11-01 Tweaks for the thumb down key
    1. fillet the front corners. Those corners tend to bulge out a bit when
    printed, and can rub against the cluster body.
    2. expand the hole in the cluster below the down key, to prevent rubbing
    3. Widen the post that has the magnet, to avoid splitting it when inserting
    a magnet
    4. Narrow the slot in the cluster for the down key post. This gives a bit
    more room between that slot and the hole for the magnet on the bottom.
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2020-11-01 Get rid of the old insertion cutout for the lower outer keywell
    The cutout wasn't present in the new design anyway, and I wasn't have
    any issues inserting the magnets without it.
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2020-11-03 Update the names for the LEDs and PTs on the finger cluster pcb
    Q -> PT
    D -> IR
    [cluster.kicad_pcb, cluster.sch]
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2020-11-03 Add a nub indicating the lens on the IR and PT footprints
    [cluster.kicad_pcb, cluster.sch, thumb_cluster_left.kicad_pcb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]
2020-11-09 Enlarge the cone angle for the attachment opening on the front clip
    This gives a bit more clearance for the standoffs
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2021-04-24 Flatten out the bottom of the key well and shorten it by .6mm
    This truncates the "V" bottom, so we can shorten the bottom of the key well
    a bit.
    This will make the outside bottoms of the keywell nearly flush with the
    back of the pcb, to enable the use of a 90 degree connector, that would
    otherwise intersect the keywell sticking out past the pcb.
    This also has some other minor tweaks to ensure horizontal surfaces are
    multiples of .2mm away from the print surface (for printing with .2mm
    layer height)
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2021-04-24 Fix the orientation of the magnet void in the base for the screw supports
    The void was flipped vertically, so that the widening insertion taper was
    at the bottom of the hole. This also embiggens the holes slightly, to make
    sure they're able to slip in.
2021-04-24 Fix the pad sizes on the cluster pcb design
    The custom sizes had apparently gotten lost in the last commit
    for the kicad stuff.
    [cluster.kicad_pcb]
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2021-04-24 Don't fillet the center key hole in the cluster
    Only the center key post itself needs to be Filleted. The hole itself can
    remain square. The corners provide a good place for the slicer to place a
    seam, where it won't interfere with the fit of the key.
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2021-04-24 Move the cluster pcb connector back as far as possible
    Now that we've switched to the horizontal connector, we can push the
    connector back a bit, since it requires less clearance behind it.
    I *think* this gets the connector far away enough (barely) from the LED
    and PT for the central key that the wire can be plugged in.
2021-04-24 Update the kicad design for the finger cluster
    This brings the PCB design up to par with the current cluster design.
    [cluster.kicad_pcb, cluster.sch]
2021-04-24 Update kicad design for finger cluster
    This adds ground/+5v planes, some thicker traces, and moves the +5v pin
    to pin 1 of the connector.
    Thanks to @rutgervana for taking a look at the design and making
    suggestions/showing example improvements.
    [cluster.kicad_pcb, cluster.sch]
2021-04-24 Rotate the cluster pcb part by 180, and tweak how the sketch is created
    This matches the orientation used in the kicad design.
    Kicad didn't like the previous dxf export for some reason. But with the
    sketch defined this way, it seems to work fine.
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2021-04-24 Fix the key alignment in the thumb cluster assemblies, and re-enable them
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2021-04-24 Add a virtual "locating pin" to the cluster pcb sketch
    This gives a reference point for the origin of the sketch, so the import
    location can be set correctly when importing the outline into kicad.
    Basically, you set the grid origin in kicad to the center of the circle
    (assuming the locating pin is already in kicad) and then make a note of
    the coordinates of that point. And then, when importing the outline, you
    can specify those coordinates as the location, to ensure the origin of the
    imported outline matches that of the existing/previous outline.
    [cluster.kicad_pcb]
2021-04-24 Fix how assemblies are exported to the fusion cloud
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2021-04-24 Minor tweaks to the cluster pcb
    - Move the identifying text to the bottom layer
    - Disable some unused layers
    - Move the design so that the import position is at an even (150, 100)
    [cluster.kicad_pcb]
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2021-04-24 Fix the thumb assemblies
    There was something funky going on with the Group component
2021-04-24 Fix up the cluster and thumb_cluster_left pcbs
    Some of the nets for the pours and screw holes had gotten unassigned
    somehow
    [cluster.kicad_pcb, thumb_cluster_left.kicad_pcb]
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2021-04-28 Tweak the nut cutouts
    On the finger cluster, the nut cutout was 2.6mm tall, but it wasn't aligned
    with a .2mm layer line, so it was actually 2.8mm tall once sliced. This
    increases the size to 2.8mm and aligns it to a .2mm layer line.
    For the thumb clusters, the size was 2.6mm tall and it was already aligned,
    but 2.6mm was a bit too short and the nut didn't fit. This increases the
    size to 2.8mm.
2021-04-28 Lengthen the main board
    Need a bit more space for the PCB design.
    This also reduces the height of the slot in the handrests that the
    main board goes into, to avoid the longer slot from clipping into the
    top of the handrest.
2021-04-28 Add kicad design for the main board
    Some high-level differences from the v1 main board
    - ESP32S2-WROOM
    - A usb-c port for usb connection to the host
    - Another usb-c port for intra-side communication (via serial.. not actually usb)
    - Discrete transistors for energizing individual clusters
    - Elimites the LED driver chip, which was a bit of an expensive specialty chip
    - Transimpedance amplifiers for amplifying the phototransistors
    - Allows for faster response times and higher sensitivity, which allows for lower
    LED currents, and shorter duty cycles -- both of which reduce power draw.
    [main_board.kicad_pcb, main_board.sch]
2021-04-28 Update thumb cluster pcbs to v0.2
    This shuffles the switch numbering and order on the connector,
    so that the center key is on the same pin of the connector (pin 4)
    as the center key of the finger clusters.
    These keys on the thumb and finger clusters have inverted logic from
    all the other keys, due to the physical design of the switches. This
    puts the inverted keys on the same pin/column. This simplifies the
    firmware a bit, because it can just assume that pin is always inverted.
    [thumb_cluster_left.kicad_pcb, thumb_cluster_left.sch, thumb_cluster_right.kicad_pcb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]
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2021-05-09 Tweak the thumb mode keys for better printability
    This adds a small "extension" to the beginning of the angled part that
    keeps it attached to the bed. The very first part of the slope up would
    always merge too strongly with the supports, leaving a bit of support
    material on the back.
    This gives a bit more vertical room at the point where the supports start,
    to help alleviate this problem.
2021-05-09 Update the various sensitivity-related resistor values
    This updates the transimpedance amplifier resistors to 2k, and adjusts
    the LED drive resistors to an appropriate level, from empirical testing.
    [cluster.kicad_pcb, cluster.sch, main_board.kicad_pcb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]
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2021-05-09 Switch out screw_13 for screw_11
    The screw with 13mm threaded length was a bit too long to fully
    cover the possible lengths between the crossover from the short
    screw. 11mm is still plenty long, and ensures full coverage of
    the possible screw+base lengths.
2021-05-18 Update the handrest model to a brep based on a t-spline
    This is a t-spline that I modeled and fit to the original handrest mesh.
    The t-spline should be more easily editable if needed.
    [left_handrest.f3d, left_handrest_scan_reduced_brep.f3d]
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2021-05-22 Update the handrest for the new main board and upcoming base design
    - Ensure the bottom of the handrest model is flat
    - Reorient the handrest model
    - Add the antenna extrusion to the central pcb
    - Make the slot long enough for the central pcb + antenna
    - Shorten the back of the slot, to ensure enough thickness betwen
    top of slot and top of handrest.
    [left_handrest.f3d]
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2021-05-24 Refactor the lalboard script to use MemoizableDesign
    This will reduce the time to run things like the upcoming full assembly,
    and the export_parts script.
    This change doesn't actually add the @MemoizeComponent decorators to speed
    things up, but mostly just converts all of the functions in lalboard to
    member functions, in preparation for adding the decorators.
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2021-05-29 Add a more generalized method for placing clusters
    This allows the clusters to be placed in a variety of ways. And in
    particular to be easily placed relative to each other, so they are
    touching.
    [absolute_cartesian_and_euler_placement.f3d, absolute_cartesian_and_euler_placement_left.f3d, absolute_cartesian_and_euler_placement_right.f3d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]
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2021-06-01 Separate out the addition of standoffs to a separate method
    This also makes adding the front clip optional in
    positioned_cluster_assembly.
    These components won't be needed for the upcoming static base.
2021-06-01 Fix the thumb pcb for positioned_thumb_assembly for the left hand
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2021-06-05 Fix the screw support placement
    This was broken by a fix in the way the normals are calculated in
    fscad.
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2021-06-06 Enlarge the back part of the hole for the thumb down key
    Sometimes, if you pressed the down key just right, it was push over against
    the wall, with an unpleasant rubbing feel/sound. This makes the hole under
    the key flare out slightly toward the end, to hopefully help reduce that.
2021-06-06 Improve the holes for the mounting magnets on the undersides of the clusters
    This adds a bit of an inward flare at the bottom of the holes, to help avoid
    glue from squeezing out, and interfering with the magnet fitting into the
    hole on the other side
2021-06-09 Reverse the cluster connectors on the main board
    This reverses the connectors, so the orientation is correct for a normally
    wired cable.
    [main_board.kicad_pcb, main_board.sch]
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2021-06-10 Use Thicken instead of OffsetEdges in static_cluster_support
    This uses Thicken instead of OffsetEdges to generate the sides of the
    support of a certain thickness.
    OffsetEdges is a bit broken on more complex geometry, and wasn't working
    well in this case.
2021-06-11 Change down the thumb down key's travel is limited
    This removes the sloped stops on the sides of the hole underneath the down
    key. Instead, a post is added to the bottom of the down key at the tip. The
    post will hit the pcb and stop the key travel.
    I'm not happy with the movement or feel of the thumb down keys. The sloped
    stops are a bit problematic, especially if the key is pressed toward the
    side, which can cause the edge of the key to slide down the sloped stop a
    bit, and skew the whole key in the y axis (the direction the thumb is
    pointing).
    This should provide a firmer stop, and prevent the key from rotating like
    that when pressed on the side.
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2021-06-14 Fix the support generation for the thumb clusters
    This fixes the generation of screw supports for the thumb clusters in the
    steel base full assemblies
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2023-10-10 Add a front magnet to the clusters
    Add a magnet, instead of that silly clip thing.
    An extra clip on the front isn't normally needed now, but one can
    be added in cases where the front of the cluster is too low to the
    base plate, to give a bit more room for the support underneath.
    This also tweaks the static supports to have another magnet at the
    front to attach to the cluster, and moves the cord slot a bit, to
    avoid the new magnet.
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2023-11-09 Use deep magnet holes on the bottoms of the palm rests
    The idea here is to use deep magnets on both sides, and then a third
    magnet in the middle, spanning the gap. I think this should help prevent
    the issues I was having with the magnets that stick out on the palm rest
    from getting unglued and coming out.
2023-11-13 Remove cutouts that are no longer needed, on the central pcb spacer
2023-11-18 Main board v2.5.1
    - Remove the decoupling capacitor on the boot selection button
    - Fix the part selection in the BOM for the 27 ohm usb series resistors
    (old part was mistakenly a 27kohm resistor)
    [main_board.kicad_pcb, main_board.kicad_sch, main_board_bom_jlc.csv]
2023-11-19 Cluster pcb v2.5.1
    - Make the slot for the center key wider, to avoid the nickel strip
    catching on the edge when pressing the center key
    - Fix the PT/LED placements for the north keywell. They were very
    slightly offset from where they should be
    - Minor component/trace placement changes, due to the widened center
    key slot
    [cluster.kicad_pcb]
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2025-04-10 Added correct LCSC part number for USB termination resistor
    [main_board.kicad_pcb, main_board.kicad_sch]
